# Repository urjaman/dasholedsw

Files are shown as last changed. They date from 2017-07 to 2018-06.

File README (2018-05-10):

I suppose i need a mission statement for this thing :P

It's a lil car widget, where the firmware is derived from a previous car widget (carlcdp).
Previously the mission was to:
- display two voltages
- control a relay based on a voltage

Other things were bonus features, like the temperature display, clock and whatnot things

This device has a mission to take in data:
- RPM pulse
- speedometer pulse
- fuel sensor voltage
(other things too, but those are bonus)

and process it into features:
- odometer 
 - trip meter
- speedometer
- RPM display

- fuel level display 
 - longer-scale derived displays like l/100km

(again, other things too, but these are the primary ones)

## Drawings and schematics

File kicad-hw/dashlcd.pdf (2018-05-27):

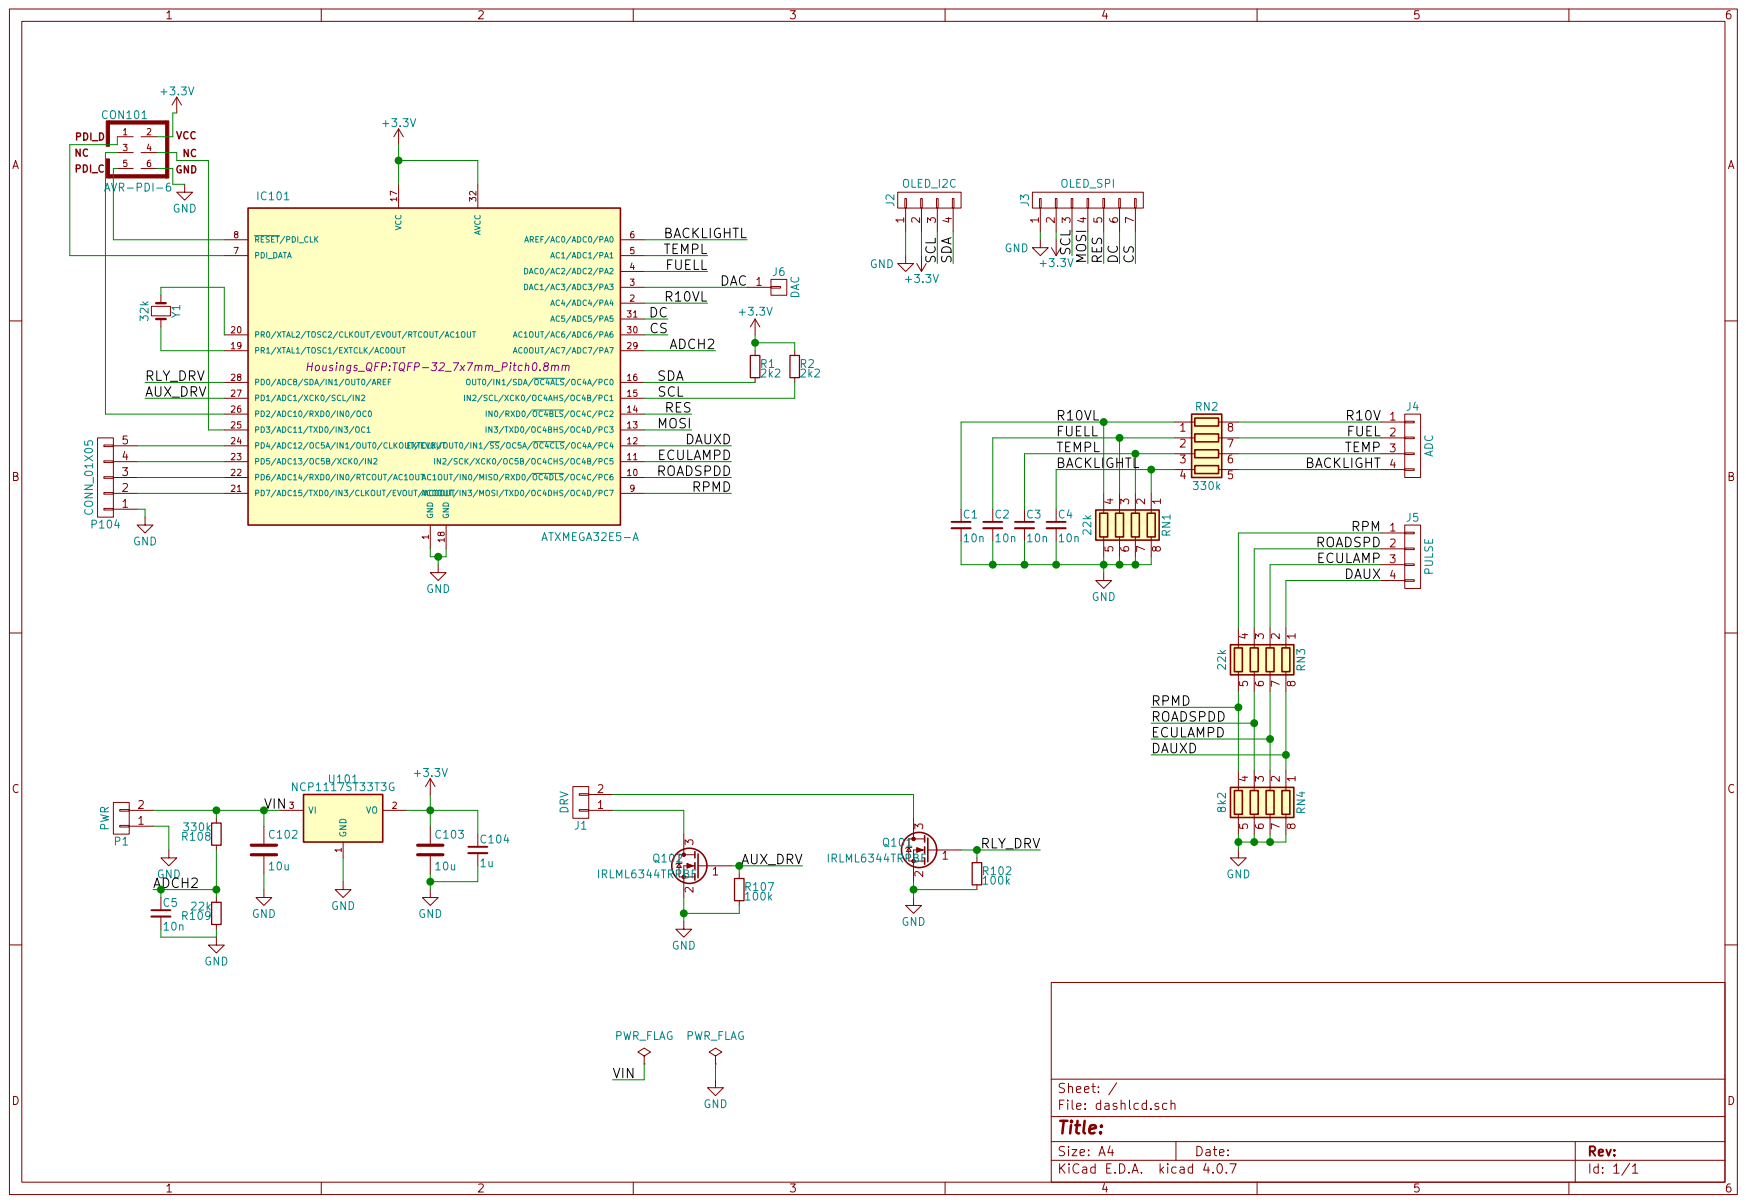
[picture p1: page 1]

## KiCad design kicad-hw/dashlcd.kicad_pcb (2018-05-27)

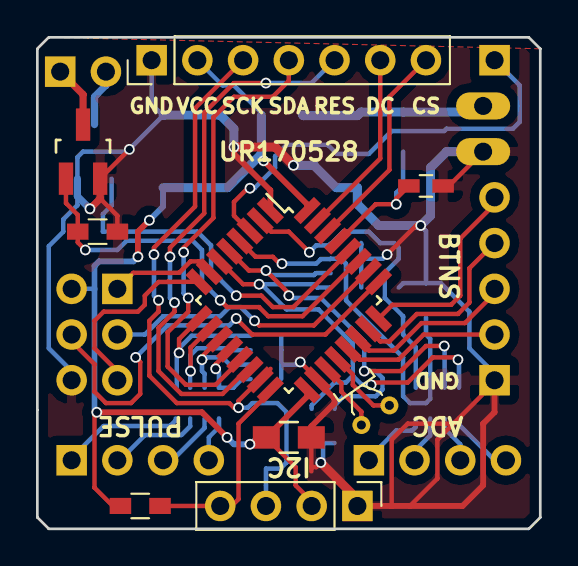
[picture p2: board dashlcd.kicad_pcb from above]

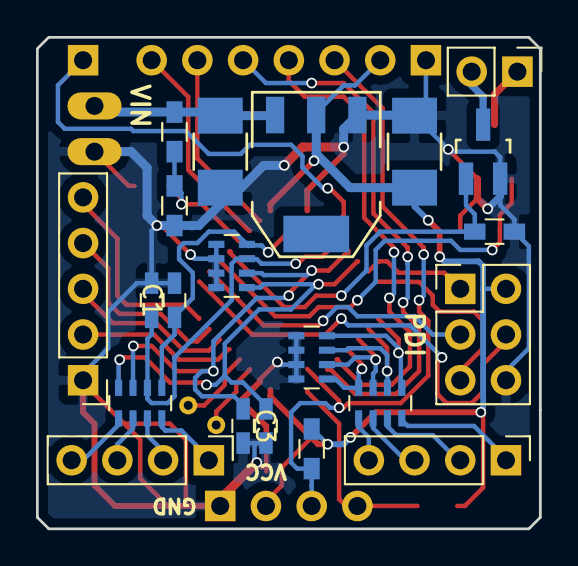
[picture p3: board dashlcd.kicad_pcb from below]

Board: 2 copper layers, 27.9 x 27.3 mm, 32 parts (23 on the bottom side), 41 nets.

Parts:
C1, C2, C3, C4, C5: .1u; C_0603_HandSoldering
C102, C103: 10u; C_1210_HandSoldering
C104: 1u; C_0805_HandSoldering
CON101: AVR-PDI-6; Pin_Header_Straight_2x03_Pitch2.54mm
IC101: ATXMEGA32E5-A; TQFP-32_7x7mm_Pitch0.8mm
J1: DRV; Pin_Header_Straight_1x02_Pitch2.54mm
J2: OLED_I2C; Pin_Header_Straight_1x04_Pitch2.54mm
J3: OLED_SPI; Pin_Header_Straight_1x07_Pitch2.54mm
J4: ADC; Pin_Header_Straight_1x04_Pitch2.54mm
J5: PULSE; Pin_Header_Straight_1x04_Pitch2.54mm
J6: DAC; Pin_Header_Straight_1x01_Pitch2.54mm
P1: PWR; PINHEAD1-2
P104: CONN_01X05; Pin_Header_Straight_1x05_Pitch2.54mm
Q101, Q102: IRLML6344TRPBF; SOT-23_Handsoldering
R1, R2: 2k2; R_0603_HandSoldering
R102, R107: 4k7; R_0603_HandSoldering
R108: 330k; R_0603_HandSoldering
R109: 22k; R_0603_HandSoldering
RN1, RN3: 22k; R_Array_Concave_4x0603
RN2: 330k; R_Array_Concave_4x0603
RN4: 8k2; R_Array_Concave_4x0603
U101: NCP1117ST33T3G; SOT-223
Y1: 32k; Crystal_DS26_d2.0mm_l6.0mm_Horizontal

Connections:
+3V3: C103.1, C104.1, CON101.2, IC101.17, IC101.32, J2.2, J3.2, R1.1, R2.1, U101.2
/ADCH2: C5.1, IC101.29, R108.1, R109.2
/AUX_DRV: IC101.27, Q102.1, R107.1
/BACKLIGHT: J4.4, RN2.5
/BACKLIGHTL: C4.1, IC101.6, RN1.1, RN2.4
/CS: IC101.30, J3.7
/DAC: IC101.3, J6.1
/DAUX: J5.4, RN3.1
/DAUXD: IC101.12, RN3.8, RN4.1
/DC: IC101.31, J3.6
/ECULAMP: J5.3, RN3.2
/ECULAMPD: IC101.11, RN3.7, RN4.2
/FUEL: J4.2, RN2.7
/FUELL: C2.1, IC101.4, RN1.3, RN2.2
/MOSI: IC101.13, J3.4
/R10V: J4.1, RN2.8
/R10VL: C1.1, IC101.2, RN1.4, RN2.1
/RES: IC101.14, J3.5
/RLY_DRV: IC101.28, Q101.1, R102.1
/ROADSPD: J5.2, RN3.3
/ROADSPDD: IC101.10, RN3.6, RN4.3
/RPM: J5.1, RN3.4
/RPMD: IC101.9, RN3.5, RN4.4
/SCL: IC101.15, J2.3, J3.3, R2.2
/SDA: IC101.16, J2.4, R1.2
/TEMP: J4.3, RN2.6
/TEMPL: C3.1, IC101.5, RN1.2, RN2.3
/VIN: C102.1, P1.2, R108.2, U101.3
GND: C1.2, C2.2, C3.2, C4.2, C5.2, C102.2, C103.2, C104.2, CON101.6, IC101.1, IC101.18, J2.1, J3.1, P1.1, P104.1, Q101.2, Q102.2, R102.2, R107.2, R109.1, RN1.5, RN1.6, RN1.7, RN1.8, RN4.5, RN4.6, RN4.7, RN4.8, U101.1
unnamed: CON101.1, IC101.7
unnamed: CON101.3, IC101.26
unnamed: CON101.4, IC101.25
unnamed: CON101.5, IC101.8
unnamed: IC101.19, Y1.2
unnamed: IC101.20, Y1.1
unnamed: IC101.21, P104.2
unnamed: IC101.22, P104.3
unnamed: IC101.23, P104.4
unnamed: IC101.24, P104.5
unnamed: J1.1, Q102.3
unnamed: J1.2, Q101.3

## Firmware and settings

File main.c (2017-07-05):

#include "main.h"
#include <avr/power.h>
#include "uart.h"
#include "console.h"
#include "appdb.h"
#include "lib.h"
#include "timer.h"
#include "backlight.h"
#include "lcd.h"
#include "buttons.h"
#include "adc.h"
#include "relay.h"
#include "tui.h"
#include "pulse.h"
#include "saver.h"
#include "eecounter.h"
#include "odo.h"

#ifdef ENABLE_UARTIF
#define RECVBUFLEN 64
const unsigned char prompt[] PROGMEM = "\x0D\x0AX32E5>";
unsigned char recvbuf[RECVBUFLEN];
unsigned char token_count;
unsigned char* tokenptrs[MAXTOKENS];

static void uartif_run(void)
{
	void(*func)(void);
	if (getline_mc(recvbuf,RECVBUFLEN)) {
		tokenize(recvbuf,tokenptrs, &token_count);
		if (token_count) {
			func = find_appdb(tokenptrs[0]);
			func();
		}
		sendstr_P((PGM_P)prompt);
	}
}
#else
static void uartif_run(void) { }
#endif


void mini_mainloop(void)
{
	timer_run();
	adc_run();
	backlight_run();
	relay_run();
	pulse_run();
	odo_run();
	eec_run();
	uartif_run();
}

void main (void) __attribute__ ((noreturn));

static void xmega_clocks(void)
{
	OSC.CTRL = OSC_RC32MEN_bm; //enable 32MHz oscillator
	while(!(OSC.STATUS & OSC_RC32MRDY_bm));	//wait for stability
	CCP = CCP_IOREG_gc; //secured access
	CLK.CTRL = 0x01; //choose this osc source as clk
}

/* VPORT0 = A, VPORT1 = C, VPORT2 = D, VPORT3 = R */
static void xmega_pins(void)
{
#if 0
	PORTCFG_MPCMASK = 0x03;
	PORTR_PIN0CTRL = PORT_OPC_PULLUP_gc;



	VPORT1_OUT = 0x10;
	VPORT1_DIR = 0xFF;

#endif

	PORTCFG_MPCMASK = 0x97;
	PORTA_PIN0CTRL = PORT_ISC_INPUT_DISABLE_gc;

	PORTCFG_MPCMASK = 0xFC;
	PORTD_PIN0CTRL = PORT_OPC_PULLUP_gc;
	VPORT2_OUT = 0x08;
	VPORT2_DIR = 0x0B;

}

void main(void)
{
	cli();
	xmega_clocks();
	xmega_pins();
	timer_init();
	uart_init();
	lcd_init();
	backlight_init();
	buttons_init();
	adc_init();
	relay_init();
	pulse_init();
	eec_init();
	odo_init();
	tui_init();
	saver_load_settings(); // we load, but dont report errors
	PMIC_CTRL = 0x87;
	sei();
#ifdef ENABLE_UARTIF
	sendstr_P((PGM_P)prompt); // initial prompt
#endif
	for(;;) {
		mini_mainloop();
		tui_run();
	}
}

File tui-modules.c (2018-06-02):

#include "main.h"
#include "tui.h"
#include "tui-lib.h"
#include "tui-mod.h"
#include "adc.h"
#include "relay.h"
#include "timer.h"
#include "pulse.h"
#include "lib.h"
#include "lcd.h"
#include "speedo.h"
#include "odo.h"

int null_ps(uint8_t prv);
int null_ps(uint8_t prv)
{
	(void)prv;
	return 0;
}

static void tui_modfinish(uint8_t*t, uint8_t ml, uint8_t x, uint8_t w)
{
	t[ml] = 0;
	uint8_t mw = lcd_strwidth(t);
	if (mw > w) mw = w; // this is a problem, but i'll leave that for the mods to avoid,
	//  this just fixes math locally here :P
	uint8_t cl = w - mw;
	if ((x+w) >= LCDWIDTH) { // right align
		lcd_clear_dw(cl);
		lcd_puts_dw(t);
	} else {
		lcd_puts_dw(t);
		lcd_clear_dw(cl);
	}
}

static uint8_t tui_ch_char(uint8_t ch)
{
	if (ch==ADC_CH_BACKLIGHT) return 'L';
	if (ch==ADC_CH_TEMP) return 'T';
	if (ch==ADC_CH_FUEL) return 'F';
	if (ch==ADC_CH_R10V) return 'R';
	if (ch==ADC_CH_MB) return 'M';
	return '?';
}

static const unsigned char tui_adcch_s0[] PROGMEM = "BACKLIGHT";
static const unsigned char tui_adcch_s1[] PROGMEM = "TEMP";
static const unsigned char tui_adcch_s2[] PROGMEM = "FUEL";
static const unsigned char tui_adcch_s3[] PROGMEM = "10V REF";
static const unsigned char tui_adcch_s4[] PROGMEM = "INPUT VOLTS";
static PGM_P const tui_adcch_table[] PROGMEM = {
	(PGM_P)tui_adcch_s0,
	(PGM_P)tui_adcch_s1,
	(PGM_P)tui_adcch_s2,
	(PGM_P)tui_adcch_s3,
	(PGM_P)tui_adcch_s4,
	(PGM_P)tui_exit_menu,
};

int tui_adcsel(uint8_t par);
int tui_adcsel(uint8_t par)
{
	par = tui_gen_listmenu(PSTR("ADC CHANNEL"), tui_adcch_table, 6, par);
	if (par >= 5) return -1;
	return par;
}

static void tui_gbv_mod(uint8_t x, uint8_t c1, uint8_t c2, uint16_t v)
{
	uint8_t mb[9];
	mb[0] = c1;
	mb[1] = c2;
	adc_print_v(&(mb[2]),v);
	tui_modfinish(mb,8,x,8*LCD_CHARW);
}

TUI_MOD(tui_bv_mod,tui_adcsel,"Volts (AVG)",8*LCD_CHARW,1)
{
	tui_gbv_mod(x, tui_ch_char(par), ':', adc_read_ch(par));
}

TUI_MOD(tui_maxbv_mod,tui_adcsel,"Volts (MAX)",8*LCD_CHARW,1)
{
	tui_gbv_mod(x, tui_ch_char(par), '+', adc_read_maxv(par));
}

TUI_MOD(tui_minbv_mod,tui_adcsel,"Volts (MIN)",8*LCD_CHARW,1)
{
	tui_gbv_mod(x, tui_ch_char(par), '-', adc_read_minv(par));
}

TUI_MOD(tui_ripple_mod,tui_adcsel,"Ripple",8*LCD_CHARW,1)
{
	tui_gbv_mod(x, tui_ch_char(par), 'R', adc_read_maxv(par)-adc_read_minv(par));
}


TUI_MOD(tui_rlst_mod,null_ps,"Relay Info",5*LCD_CHARW,1)
{
	uint8_t mb[6];
	mb[0] = 'R';
	mb[1] = ':';
	switch (relay_get_mode()) {
		default:
		case RLY_MODE_OFF:
			mb[2] = '0';
			break;
		case RLY_MODE_ON:
			mb[2] = '1';
			break;
		case RLY_MODE_AUTO:
			mb[2] = 'A';
			break;
	}
	mb[3] = '>'; // "->"-like char
	switch (relay_get()) {
		default:
		case RLY_MODE_OFF:
			mb[4] = '0';
			break;
		case RLY_MODE_ON:
			mb[4] = '1';
			break;
	}
	tui_modfinish(mb,5,x,5*LCD_CHARW);
}


static const unsigned char tui_pch_s0[] PROGMEM = "DAUX";
static const unsigned char tui_pch_s1[] PROGMEM = "ECULAMP";
static const unsigned char tui_pch_s2[] PROGMEM = "ROADSPD";
static const unsigned char tui_pch_s3[] PROGMEM = "RPM";
static PGM_P const tui_pch_table[] PROGMEM = {
	(PGM_P)tui_pch_s0,
	(PGM_P)tui_pch_s1,
	(PGM_P)tui_pch_s2,
	(PGM_P)tui_pch_s3,
	(PGM_P)tui_exit_menu,
};

int tui_pulsesel(uint8_t par);
int tui_pulsesel(uint8_t par)
{
	par = tui_gen_listmenu(PSTR("Channel"), tui_pch_table, 5, par);
	if (par >= 4) return -1;
	return par;
}


TUI_MOD(tui_pstate_mod,tui_pulsesel,"Edge Ctr",8*LCD_CHARW,1)
{
	uint8_t buf[9];
	uint16_t e;
	uint8_t s = pulse_state(par+4, &e);
	buf[0] = '4'+par;
	buf[1] = ':';
	buf[2] = '0'+s;
	buf[3] = '|';
	uchar2xstr(buf+4, e>>8);
	uchar2xstr(buf+6, e&0xFF);
	tui_modfinish(buf,8,x,8*LCD_CHARW);
}

TUI_MOD(tui_pulsehz_mod,tui_pulsesel,"Freq",9*LCD_CHARW,1)
{
	uint8_t buf[10];
	uint24_t hz = pulse_get_hz(par+4, NULL);
	buf[0] = '4'+par;
	buf[1] = ':';
	uint24_t hzi = hz >> PULSE_HZ_SHIFT;
	if (hzi>99999) hzi = 99999;
	uint8_t n = luint2str(buf+2, hzi) + 2;
	buf[n] = '.';
	buf[n+1] = '0' + ( (hz & (_BV(PULSE_HZ_SHIFT)-1) * 10) >> PULSE_HZ_SHIFT );
	buf[n+2] = 0;
 	tui_modfinish(buf,n+2,x,9*LCD_CHARW);
}


TUI_MOD(tui_speedo_mod,null_ps,"Speedo", 6*LCD_CHARW,2)
{
	const uint8_t lcdw = 6*LCD_CHARW;
	uint8_t buf[8];
	uint16_t kmh = (speedo_get_kmh10()+5)/10;
	if (kmh>999) kmh=999;
	uint2str(buf,kmh);
	uint8_t off = lcdw - lcd_strwidth_big(buf);
	lcd_clear_big_dw(off);
	lcd_puts_big(buf);
}

TUI_MOD(tui_big_speedo_mod,null_ps,"Big Speedo", 12*LCD_CHARW, 4)
{
	const uint8_t lcdw = 12*LCD_CHARW;
	uint8_t buf[8];
	uint16_t kmh = (speedo_get_kmh10()+5)/10;
	if (kmh>999) kmh=999;
	uint2str(buf,kmh);
	uint8_t off = lcdw - lcd_strwidth_dbig(buf);
	lcd_clear_dbig_dw(off);
	lcd_puts_dbig(buf);
}

TUI_MOD(tui_odometer_mod,null_ps,"Odometer", 12*LCD_CHARW, 4)
{
	uint8_t buf[8];
	uint32_t m = odo_get(NULL);
	uint24_t km = m/1000;
	m = m%1000;
	if (km>999999) km %= 1000000;
	luint2str_zp(buf, km, 6);
	tui_set_color(TTC_HL1);
	lcd_puts_big(buf);
	tui_unset_color();

	lcd_gotoxy_dw(x,y+2);
	luint2str_zp(buf, m, 3);
	lcd_puts(buf);

	PGM_P kms = PSTR("KM");
	uint8_t skip = 1*LCD_CHARW;
	lcd_clear_big_dw(skip);
	tui_set_color(TTC_HEAD1);
	lcd_puts_big_P(kms);
	tui_unset_color();
	lcd_clear_big_eol();

	lcd_gotoxy_dw(x,y+3);
	lcd_clear_dw(4*LCD_CHARW);
}
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

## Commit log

2016-03-29 switch to the mini-lcd voltage indicator thingy
2016-04-06 pcd8544: move to hw spi
2016-04-06 pcd8544: spi... better or fail, but different
2016-04-07 adc: maybe ...
2016-04-07 improved lcd stuff, clear()ier tui...
    now... why 5.16V?
2016-04-07 adc: operational :)
2016-04-07 tui: show dem adc ch's
2016-04-07 adc: flush bad sample(s) on boot
    this makes for much cleaner first reading on boot :)
2016-04-08 pcd8544: switch to async SPI code...
2016-04-08 buttons: support 1, 2, 3 or 4 buttons :P
    with 1 button you'll need to live with next or ok, but yeah
    they should be enough to navigate our menus, though slowly...
2016-04-08 improve buttons ...
2016-04-10 tui: fixup some, add some menus etc
    [tui-lib.c]
2016-04-10 make the TUI a bit easier to use with 1 button
2017-06-22 nasty menu bug fixed and menu stuff reworked lots
    [tui-lib.c]
2017-06-22 adc: support the 5 channels we have
2017-06-22 fixup/remove flicery-looking unnecessary lcd-clears
    [tui-lib.c]
2017-06-22 Implement one button mode for the TUI module editor
2017-06-24 Add the saver module (not yet functional, suspecting the avr-libc EEPROM driver, writing own...)
2017-06-24 add saver API support to backlight and relay modules
2017-06-25 move system timer to TCD5, freeing TCC4 for capture operations
    plans: TCD5 for system timer
    TCC4 for 4-channel frequency capture (one or both edges, i guess...)
    TCC5 for 1-channel frequency and duty capture
2017-06-28 fixup logic so pulse actually clears to 0 Hz properly :)
2017-06-29 moved timer subsystem to live from the 32kHz RTC module
2017-06-29 pulse: use 8192 Hz from the 32.768kHz crystal for timing
    should be able to have accurate RPM and speed ;P
2017-06-30 tui-mod: encode module count in stored EEPROM size
    this way we can freely change TUI_MODS_MAX without breaking compatibility,
    and save a byte (plus 4* unused module slots) of EEPROM :)
2017-07-01 implement a couple of speedometers
2018-05-27 Boot logo support :)
    My current logo i'm using is copyrighted so you dont get logo.gif,
    but maybe i'll put some test data in later, also you can just
    make your own 96x64 low-color gif you like :)
2018-05-27 Add the kicad hardware files
    [dashlcd.kicad_pcb, dashlcd.sch]
2018-05-28 USART MSPIM for LCD SPI support (untested, yet)
2018-05-28 fixup that MSPIM support, and change it to ISR-less
    the display is initialized and used so early that we dont have
    interrupts running, maybe to be fixed but work with that.
    [ssd1331.c]
2018-05-28 cleanup the OLED driver (get rid of the bitbang option etc)
2018-05-30 pretty RPM gauge, to be redesigned, but for storage :P
    [tui-modules.c]
